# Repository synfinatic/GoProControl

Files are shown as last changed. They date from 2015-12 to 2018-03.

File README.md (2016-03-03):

# GoProControl

## About

I wanted an easy way to syncronize my GoPro videos with the data generated from
my data logger.  In the past, I've done this manually with
[DashWare](http://www.dashware.net), but it is a tedious manual process to get
them syncronized.  There had to be a better way!

I realized that many GoPro's (GoPro3 Silver/Black, GoPro4, etc) have built in
WiFi and we all know about the iPhone and Android apps.  So clearly there was a
way to controll them via WiFi.

GoProControl is a simple box you can plug into your car or motorcycle and
connect to your datalogger's digital output or input sensor.  I use the
inexpensive [ESP8266](http://www.esp8266.com/) to control the a GoPro.  In the
future, I hope to be able to control multiple GoPro's like the [GoPro
Remote](http://shop.gopro.com/accessories/smart-remote/ARMTE-002.html) can.

## How it works

GoProControl has 4 pins:

 1. +5-12V
 2. GND
 3. Digital Input 
 4. Digital Ouput
 
When GoProControl is turned on, it will send a signal to the GoPro to also turn
on- which may take a few seconds.  When the Digital Input is connected to
ground (GND) it will tell the GoPro to start recording. 

When the Digital Input is disconnected from ground (floating or +3.3-12V) it
will tell the GoPro to stop recording.  You should configure your GoPro to
auto-off after 60seconds to save battery.

Note, when the Digital Input is connected to ground, the Digital Output will be
driven to 3.3V.  This is so if your data logger does not have an output channel
you can control, you can use a simple toggle switch to both turn on the GoPro
and mark the time when recording started in your data logger using an input
channel on your data logger.

**Note:** If you have the option of powering this by 5 or 12V, use 5V.  If
using your vehicle's battery, be sure it is switched with the ignition to
prevent draining your battery as this circuit uses ~330mA.

## Programming

The GoProControl board has an onboard connector for programming via a FTDI
cable.  This cable should provide 5V of power and can use either 3.3V or 
5V for signalling.

Configure your GoPro WiFi for "App Mode" and define a SSID and WiFi Password.

Before programming your GoProController, you first need to edit 
**src/goprocontrol/goprocontrol.ino** and edit the SSID and WIFI_PASSWORD
to match your GoPro's settings.

In order to program your GoProController, you will need to start the Arduino
application and figure out what serial speed (baud) your ESP8266 communicates
at.  Older boards run at 9600, while newer boards seem to run at 115200.  

Once you have figured out the serial speed, configure Arduino for a 
"Generic ESP8266 Module" and the upload speed to the same speed.  Then, 
with the board powered up:

 1. Press and hold the PROG button
 2. Press and release the RST button
 3. Release the PROG button
 4. Uplaod the sketch via the Arduino application

## Links Links to projects or information that was critical to me creating this
project.  Thank you!

 * [GoProWiFiHack](https://github.com/KonradIT/goprowifihack)
 * [GoProController](https://github.com/joshvillbrandt/GoProController)
 * [GoProHero](https://github.com/joshvillbrandt/goprohero)
 * [GoProControllerUI](https://github.com/joshvillbrandt/GoProControllerUI)

## License

GoProControl is GPLv3

## Trademarks

GoPro, GoPro3 and GoPro4 are trademark [GoPro](http://www.gopro.com).

GoProControl is not affiliated with GoPro in any way.

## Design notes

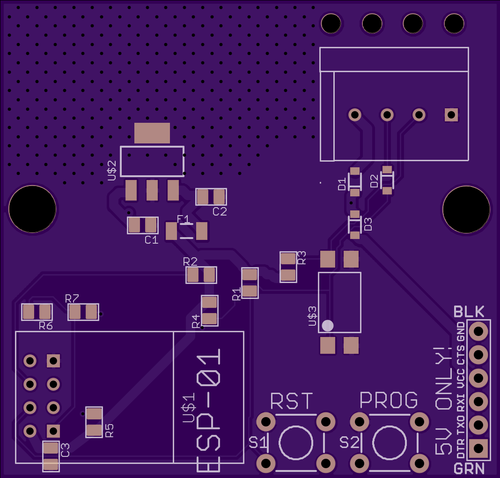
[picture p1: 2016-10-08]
images/board-top.png

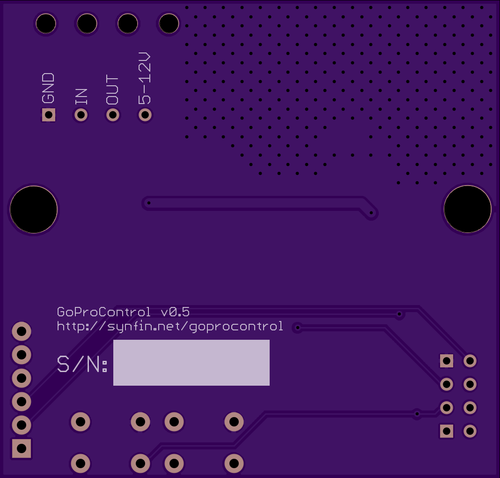
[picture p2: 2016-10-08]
images/board-bottom.png

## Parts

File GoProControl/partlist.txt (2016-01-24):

Partlist

Exported from goprocontrol.sch at 1/23/16 4:04 PM

EAGLE Version 7.5.0 Copyright (c) 1988-2015 CadSoft

Assembly variant: 

Part     Value                        Device                                      Package             Library                    Sheet

C1       1uf                          CERAMIC-1UF-25V-10%-X7R(0805)               C0805               Seeed-OPL-Capacitor        1
C2       .01uf                        CERAMIC-1UF-25V-10%-X7R(0805)               C0805               Seeed-OPL-Capacitor        1
D1       B5817WS                      SCHOTTKY-DIODE                              SOD-323             synfinatic                 1
D2       B5817WS                      SCHOTTKY-DIODE                              SOD-323             synfinatic                 1
D3       B5817WS                      SCHOTTKY-DIODE                              SOD-323             synfinatic                 1
JP1      FTDI_BASICPTH                FTDI_BASICPTH                               FTDI_BASIC          SparkFun-Connectors        1
JP2                                   M03PTH                                      1X03                SparkFun-Connectors        1
JP3      PTSA-1.5/4-3.5FOST-TE-3.5-4P PTSA-1.5/4-3.5FOST-TE-3.5-4P                TERM-4P-3.5         synfinatic                 1
R1       1k                           SMD-RES-10K-1%-1/8W(0805)                   R0805               Seeed-OPL-Resistor         1
R2       1k                           SMD-RES-10K-1%-1/8W(0805)                   R0805               Seeed-OPL-Resistor         1
R4       1k                           SMD-RES-10K-1%-1/8W(0805)                   R0805               Seeed-OPL-Resistor         1
R5       1k                           SMD-RES-10K-1%-1/8W(0805)                   R0805               Seeed-OPL-Resistor         1
R6       10K                          SMD-RES-10K-1%-1/8W(0805)                   R0805               Seeed-OPL-Resistor         1
R7       22K                          SMD-RES-22K-5%-1/8W(0805)                   R0805               Seeed-OPL-Resistor         1
S1       RESET                        SWITCH-MOMENTARY-2PTH                       TACTILE-PTH         SparkFun-Electromechanical 1
S2       PROG                         SWITCH-MOMENTARY-2PTH                       TACTILE-PTH         SparkFun-Electromechanical 1
U$1      ESP01                        ESP01                                       ESP01               esp8266modules             1
U$2      POLOLU-D24V5F3               POLOLU-D24V5FD24V5F                         POLOLU-D24V5FX      synfinatic                 1
U$3      LTV-816S                     SMD-PHOTOCOUPLER-5KV-LTV-816S(4P-4.6X6.5MM) SMD4-2.54-4.6X6.5MM Seeed-OPL-Transistor       1

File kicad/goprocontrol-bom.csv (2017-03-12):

Source | /Users/aturner/GIT/gopro-control/kicad/goprocontrol.sch
Kicad Rev | Eeschema 4.0.5
Generated Date | Saturday | March 11 | 2017 'PMt' 07:09:48 PM
Title | GoProControl with Adjustable Delay Timer
Company | Aaron Turner <synfinatic@gmail.com>
Revision | v2.0
Date Issue | 2017-03-05
Comment | https://synfin.net/goprocontrol
Comment | Advanced GoProControl
Comment | GoProControl with Power Control
Reference | Value | Library | Library Ref
P1 | CONN_01X06 | conn | CONN_01X06
U2 | ESP-01v090 | ESP8266 | ESP-01v090
SW2 | Prog | switches | SW_Push
SW1 | Reset | switches | SW_Push
R2 | 1k | device | R
R1 | 1k | device | R
C2 | 1uf | device | C
U3 | D24V5F3 | synfinatic | D24V5Fx
R13 | 1k | device | R
C5 | .01uf | device | C
U1 | NE555 | linear | NE555
RV1 | 500k | device | POT_TRIM
Q3 | MMBT3906 | transistors | MMBT3906
Q4 | MMBT3906 | transistors | MMBT3906
Q1 | MMBT3904 | transistors | MMBT3904
Q2 | MMBT3904 | transistors | MMBT3904
C1 | 0.1uf | device | C
R3 | 100k | device | R
C4 | 100uf | device | CP
R6 | 2.2k | device | R
D2 | 1n4148 | device | D
R11 | 2.2k | device | R
R9 | 10k | device | R
R10 | 2.2k | device | R
R7 | 10k | device | R
R8 | 2.2k | device | R
C3 | 0.1uf | device | C
Q5 | IRLML6344 | device | Q_NMOS_GSD
R12 | 1k | device | R
ROpt1 | 100k | device | R
FTDIProg1 | FTDI | synfinatic | FTDI
D3 | B5817WS | device | D_Schottky
D4 | B5817WS | device | D_Schottky
P2 | CONN_01X02 | conn | CONN_01X02

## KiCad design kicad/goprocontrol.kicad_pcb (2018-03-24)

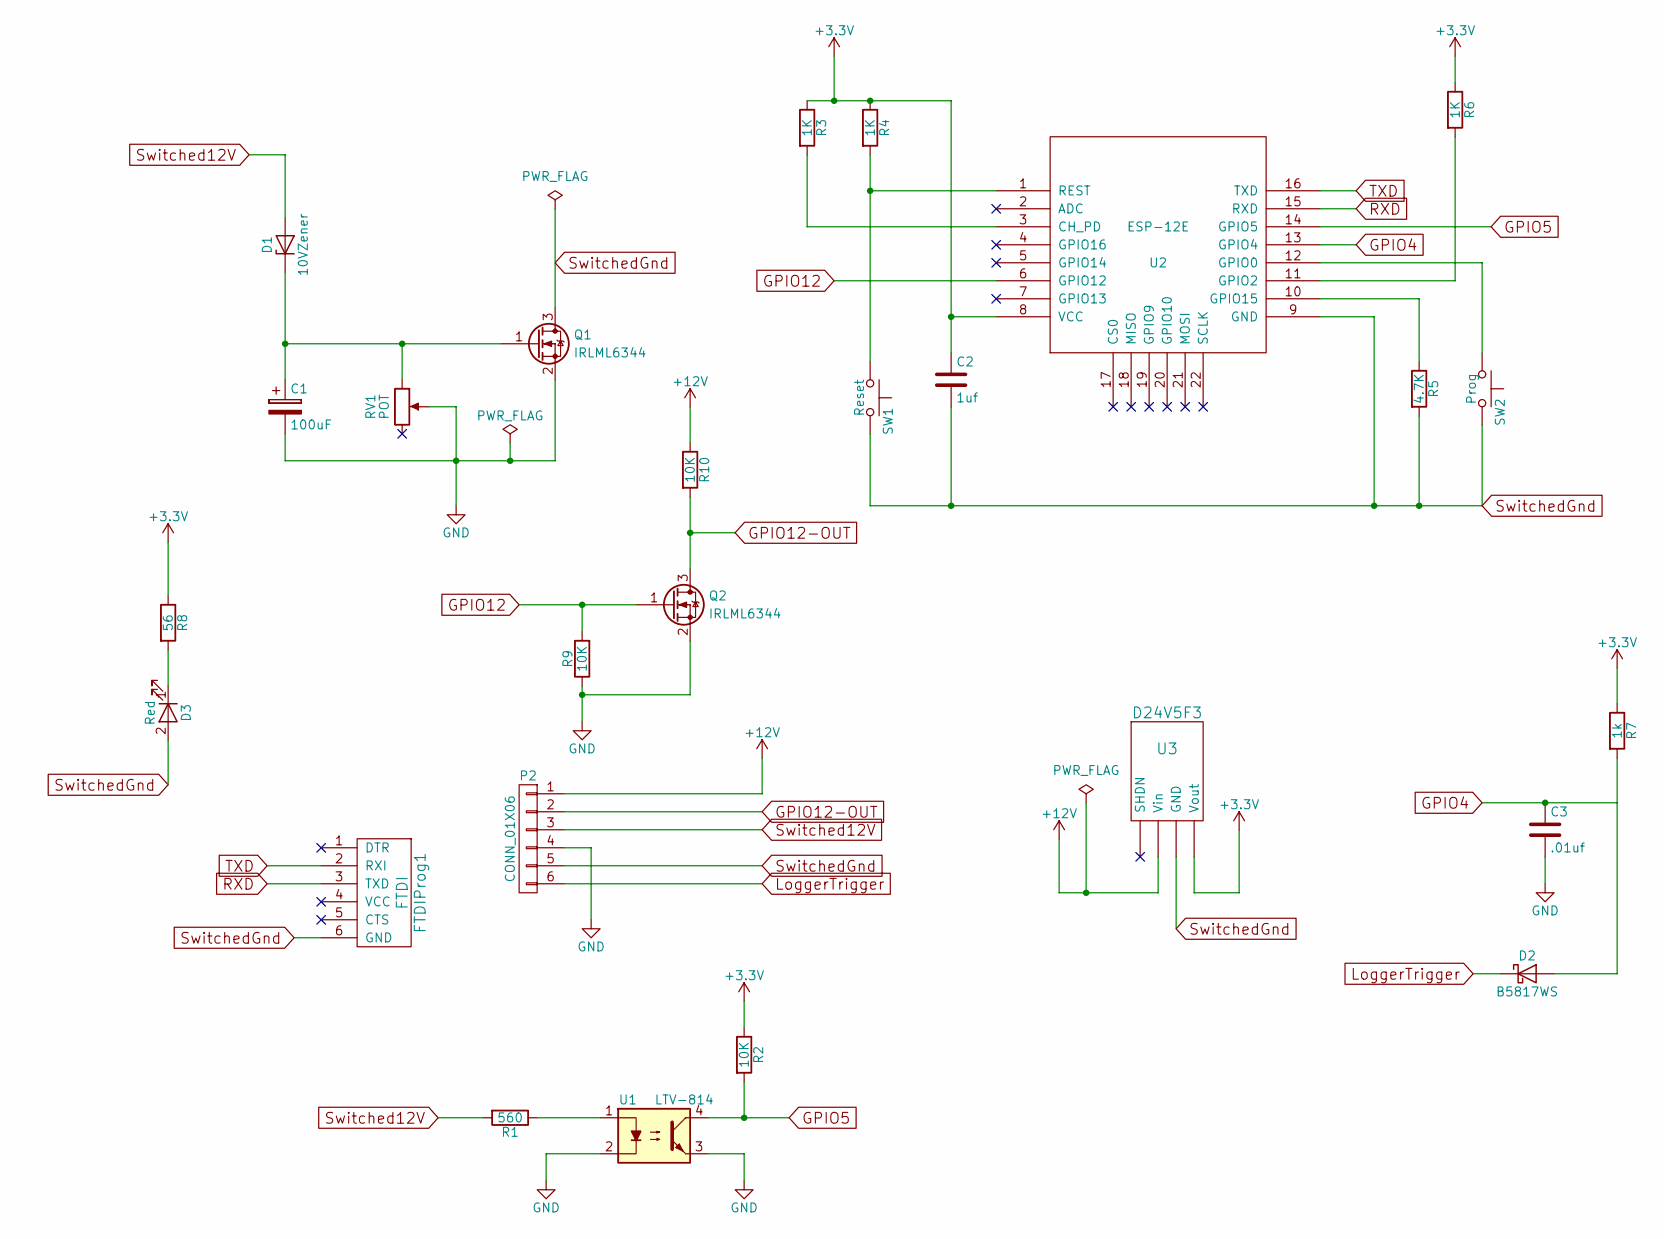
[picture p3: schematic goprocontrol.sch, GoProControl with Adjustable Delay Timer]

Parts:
C1: 100uF; CP_Elec_6.3x7.7
C2: 1uf; C_0805_HandSoldering
C3: .01uf; C_0805_HandSoldering
D1: 10VZener; D_SOD-123F
D2: B5817WS; SOD-323_HandSoldering
D3: Red; LED_0805_HandSoldering
FTDIProg1: FTDI; FTDIHeader
P2: CONN_01X06; PhoenixContact_MSTBA-G_06x5.08mm_Angled
Q1, Q2: IRLML6344; SOT-23_Handsoldering
R1: 560; R_0805_HandSoldering
R2, R9, R10: 10K; R_0805_HandSoldering
R3, R4, R6: 1K; R_0805_HandSoldering
R5: 4.7K; R_0805_HandSoldering
R7: 1k; R_0805_HandSoldering
R8: 56; R_0805_HandSoldering
RV1: POT; Potentiometer_Bourns_3296W_3-8Zoll_Inline_ScrewUp
SW1: Reset; SPST-SMD-6x3.5
SW2: Prog; SPST-SMD-6x3.5
U1: LTV-814; Optocoupler_SMD_LTV-817S
U2: ESP-12E; ESP-12E-SMD
U3: D24V5F3; D24V5Fx

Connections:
+3V3: C2.1, R2.1, R3.1, R4.1, R6.1, R7.1, R8.1, U2.8 (VCC), U3.4 (Vout)
+12V: P2.1, R10.1, U3.2 (Vin)
GND: C1.2, C3.2, P2.4, Q1.2 (S), Q2.2 (S), R9.1, RV1.2, U1.2, U1.3
GPIO4: C3.1, U2.13 (GPIO4)
GPIO5: R2.2, U1.4, U2.14 (GPIO5)
GPIO12: Q2.1 (G), R9.2, U2.6 (GPIO12)
GPIO12-OUT: P2.2, Q2.3 (D), R10.2
LoggerTrigger: D2.1 (K), P2.6
unnamed: C1.1, D1.1 (K), Q1.1 (G), RV1.1
unnamed: D2.2 (A), R7.2
unnamed: D3.1 (K), R8.2
unnamed: R1.1, U1.1
unnamed: R3.2, U2.3 (CH_PD)
unnamed: R4.2, SW1.1, U2.1 (REST)
unnamed: R5.1, U2.10 (GPIO15)
unnamed: R6.2, U2.11 (GPIO2)
unnamed: SW2.1, U2.12 (GPIO0)
RXD: FTDIProg1.3 (TXD), U2.15 (RXD)
Switched12V: D1.2 (A), P2.3, R1.2
SwitchedGnd: C2.2, D3.2 (A), FTDIProg1.6 (GND), P2.5, Q1.3 (D), R5.2, SW1.2, SW2.2, U2.9 (GND), U3.3 (GND)
TXD: FTDIProg1.2 (RXI), U2.16 (TXD)

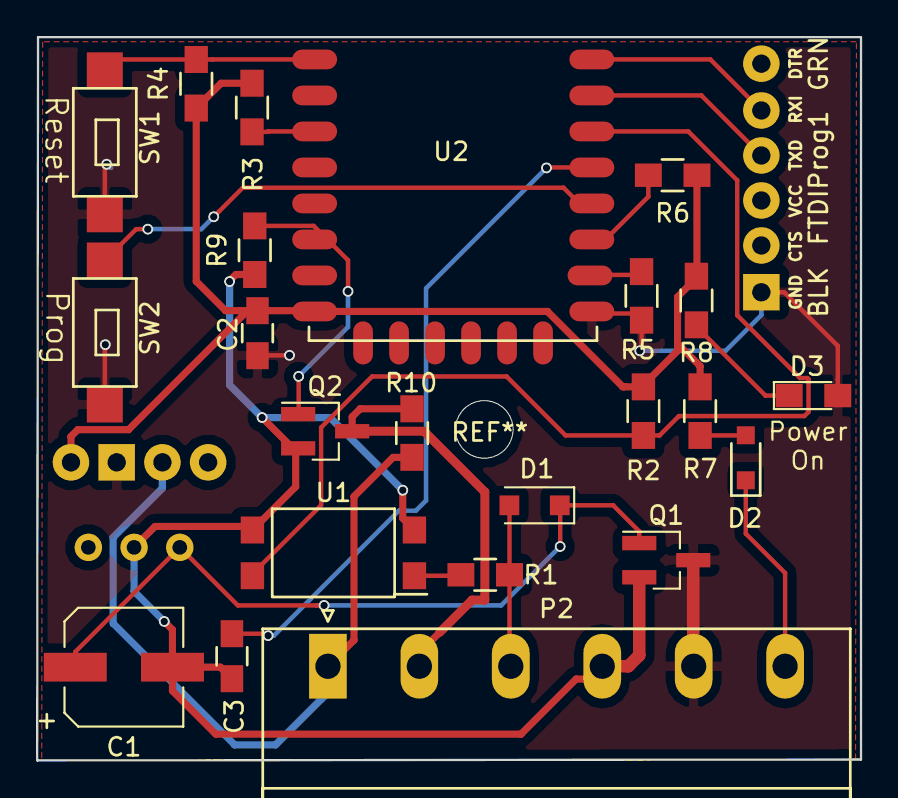
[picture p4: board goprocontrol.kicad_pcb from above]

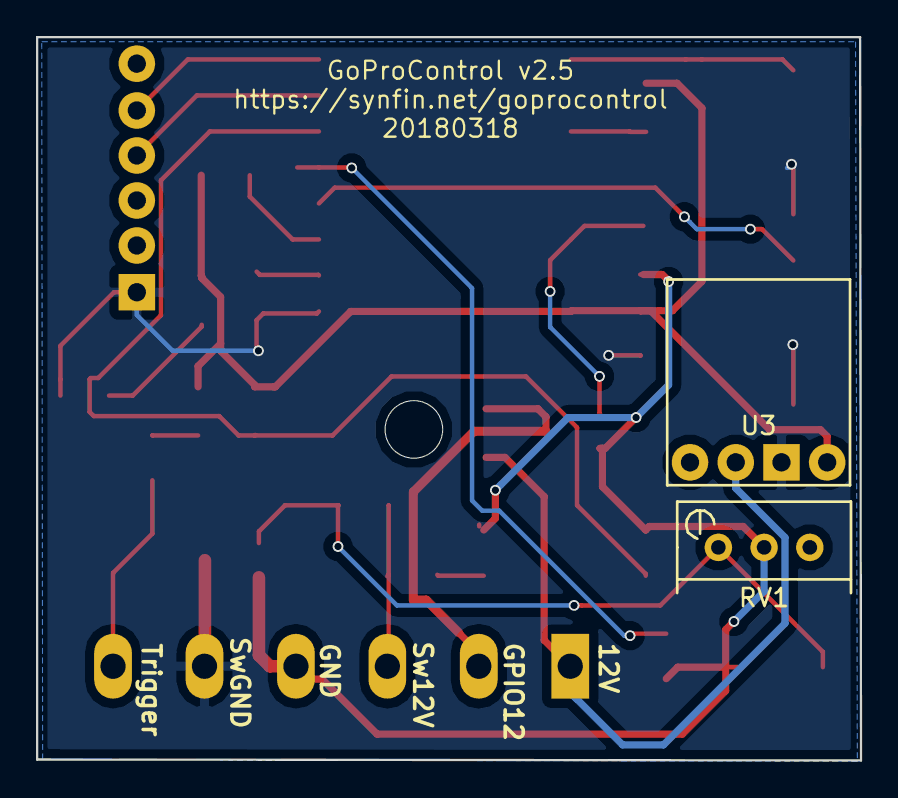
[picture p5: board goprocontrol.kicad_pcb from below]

Board: 2 copper layers, 45.8 x 40.2 mm, 26 parts (2 on the bottom side), 21 nets.

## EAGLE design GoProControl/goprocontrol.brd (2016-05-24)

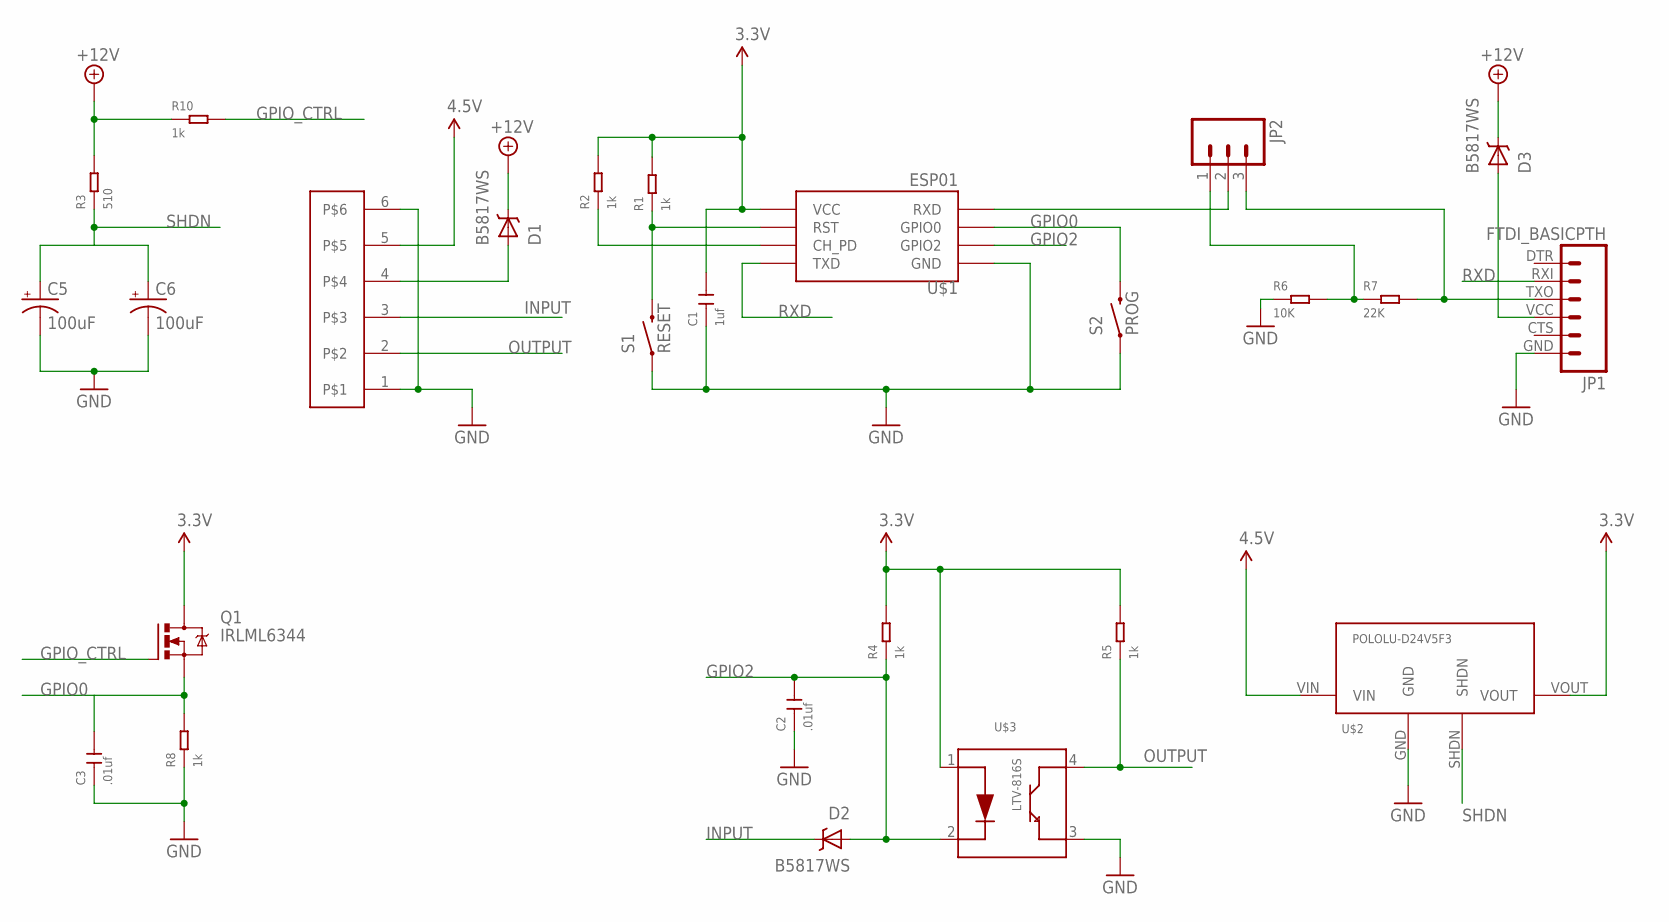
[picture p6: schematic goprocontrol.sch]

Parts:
C1: 1uf; C0805
C2, C3: .01uf; C0805
C5, C6: 100uF; CPOL-RADIAL-100UF-25V
D1, D2, D3: B5817WS; SOD-323
JP1: FTDI_BASICPTH; FTDI_BASIC
JP2: M03PTH; 1X03
Q1: IRLML6344; SOT23
R1, R2, R4, R5, R8, R10: 1k; R0805
R3: 510; R0805
R6: 10K; R0805
R7: 22K; R0805
S1: RESET; TACTILE-PTH
S2: PROG; TACTILE-PTH
U$1: ESP01
U$2: POLOLU-D24V5F3; POLOLU-D24V5FX
U$3: LTV-816S; SMD4-2.54-4.6X6.5MM
U$4: TERM-BLOCK-P6-3.5; TERM-6P-3.5

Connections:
3.3V: C1.2, Q1.3 (D), R1.2, R2.2, R4.2, R5.2, U$1.VCC, U$2.VOUT, U$3.1 (ANODE)
3.3V-TX: JP1.TXO (3), JP2.3, R7.2
5V-TX: JP2.1, R6.2, R7.1
+12V: D1.C1 (C), D3.C1 (C), R3.2, R10.1
GND: C1.1, C2.1, C3.1, C5.2 (-), C6.2 (-), JP1.GND (6), R6.1, R8.1, S1.1, S2.1, U$1.GND, U$2.GND, U$3.3 (EMITER), U$4.1, U$4.6
GPIO0: C3.2, Q1.2 (S), R8.2, S2.3 (2), U$1.GPIO0
GPIO2: C2.2, D2.A1 (A), R4.1, U$1.GPIO2, U$3.2 (CATHODE)
GPIO_CTRL: Q1.1 (G), R10.2
INPUT: D2.C1 (C), U$4.3
unnamed: R2.1, U$1.CH_PD
unnamed: R1.1, S1.3 (2), U$1.RST
unnamed: D3.A1 (A), JP1.VCC (4)
unnamed: D1.A1 (A), U$4.4
OUTPUT: R5.1, U$3.4 (COLLECTOR), U$4.2
RXD: JP1.RXI (2), U$1.TX (TXD)
SHDN: C5.1 (+), C6.1 (+), R3.1, U$2.SHDN
TXD: JP2.2, U$1.RX (RXD)
V_BATT: U$2.VIN, U$4.5

Board: 2 copper layers, 26 parts (0 on the bottom side), 18 nets, no tracks yet.

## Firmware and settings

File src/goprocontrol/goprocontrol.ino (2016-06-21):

/*
 * GoProControl
 *
 * Software for ESP8266 (ESP-01) to control a GoPro camera via
 * WiFi.  Tested with GoPro 3+ Silver/Black
 *
 * Make sure you've installed:
 *  - Arduino IDE v1.6.5+ (http://www.arduino.cc)
 *  - ESP8266 for Arduino (https://github.com/esp8266/Arduino) 
 */
#define SERIAL_SPEED 115200        // Set this to match your ESP8266 serial speed
#define GOPRO_DEBUG_WIFI 0         // Enable (1) or disable (0) debugging
#define SSID_NAME "ADTGoProBlack"  // SSID of your GoPro
#define WIFI_PASSWORD "falcon123"  // WiFi Password


#include <Arduino.h>

#include <ESP8266WiFi.h>
#include <ESP8266WiFiMulti.h>
#include <ESP8266HTTPClient.h>
#include "goprocontrol.h"

#define USE_SERIAL Serial

ESP8266WiFiMulti WiFiMulti;
char request_str[45];

typedef enum {
    START,
    STOP,
    NO_CHANGE,
    NONE
} Recording;

Recording recording = NO_CHANGE;
Recording last_mode = NONE;

/*
 * Send a HTTP request up to <retries> times with a <delay_ms> delay.
 * If retries < 0, then we will retry forever.  We'll only print an error 
 * every 10 times
 */
bool
send_request(const char *request_fmt, int retries = 5, int delay_ms = 100) {
    int httpCode, status;
    unsigned int times = 0;
    HTTPClient http;

    snprintf(request_str, 44, request_fmt, WIFI_PASSWORD);
    USE_SERIAL.printf("Sending: %s\n", request_str);

    while (((times < retries) && retries > 0) || (retries < 0)) {
        USE_SERIAL.printf("Trying run()\n");
        USE_SERIAL.flush();
        status = WiFiMulti.run();
        if ((status == WL_CONNECTED)) {
            USE_SERIAL.printf("Trying begin()\n");
            USE_SERIAL.flush();
            http.begin(GOPRO_HOST, GOPRO_PORT, request_str);
            USE_SERIAL.printf("Trying GET()\n");
            USE_SERIAL.flush();
            httpCode = http.GET();
            if (httpCode == HTTP_CODE_OK) {
                http.end();
                USE_SERIAL.printf("OK\n");
                USE_SERIAL.flush();
                return true;
            } else if (times % 10 == 0) {
                USE_SERIAL.printf("[%u] HTTP GET failed with: %d\n", times, httpCode);
                USE_SERIAL.flush();
            }
        } else if (times % 10 == 0) {
            USE_SERIAL.printf("Not connected to GoPro WiFi: %d\n", status);
            USE_SERIAL.flush();
        }
        times ++;
        delay(delay_ms);
    }

    http.end();
    USE_SERIAL.printf("Failed %d times to send request: %s", retries, request_fmt);
    USE_SERIAL.flush();
    return false;
}

void 
setup() {
    int status;

    pinMode(GPIO, INPUT);

    USE_SERIAL.begin(SERIAL_SPEED);
#ifdef GOPRO_DEBUG_WIFI
    USE_SERIAL.setDebugOutput(true);
#endif

    USE_SERIAL.println();
    USE_SERIAL.println();
    USE_SERIAL.println();

    for(uint8_t t = 4; t > 0; t--) {
        USE_SERIAL.printf("[SETUP] WAIT %d...\n", t);
        USE_SERIAL.flush();
        delay(1000);
    }

    USE_SERIAL.printf("Connecting to %s\n", SSID_NAME);
    WiFiMulti.addAP(SSID_NAME, WIFI_PASSWORD);
    status = WiFiMulti.run();
    if (status == WL_CONNECTED) {
        USE_SERIAL.printf("Connected!\n");
    } else {
        USE_SERIAL.printf("Not connected: %d\n", status);
    }
    WiFiMulti.run();
    send_request(GOPRO_ON, -1, 1000);  // Blocks until we turn on the GoPro
}


/*
 * Loop forever looking to see if we should start/stop recording
 */
void
loop() {
    if (digitalRead(GPIO) == HIGH) {
        recording = STOP;
    } else {
        // we record when it goes low!
        recording = START;
    }

    if (recording != last_mode) {
        USE_SERIAL.printf("Changing modes %u -> %u\n", last_mode, recording);
        last_mode = recording;

        if (recording == START) {
            USE_SERIAL.printf("Starting recording...\n");
            if (send_request(GOPRO_RECORD)) {
                recording = NO_CHANGE;
            }
        } else if (recording == STOP) {
            USE_SERIAL.printf("Stopping recording...\n");
            if (send_request(GOPRO_STOP)) {
                recording = NO_CHANGE;
            }
        }
    }
}

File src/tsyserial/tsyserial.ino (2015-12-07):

/*
 * Teensy Serial Application for Teensy 3.x => ESP8266
 *
 * Uses HWSerial Port 0 on Teensy 3.x to talk
 * to ESP8266.  Everything you read/write on the /dev/tty.usb*
 * port the Teensy exposes will be read/write to the ESP8266-
 * basically, it's an programmable $18 FTDI cable. :)
 *
 * Be sure to enable "Both NL and CR" in the Arduino
 * terminal if you're going to talk AT commands to the ESP8266!
 */

#include <Arduino.h>
// ESP8266 serial port speed.  Try: 115200, 9600, 57600
#define ESPSERIAL_SPEED 115200
#define LED 13

void setup() {
    Serial.begin(9600);
    Serial1.begin(ESPSERIAL_SPEED);
    pinMode(LED, OUTPUT);
}

uint32_t last = 0; 
bool led_mode;

void loop() {
    char byte;
    uint32_t now;

    if (Serial.available()) {
        byte = Serial.read();
        Serial1.write(byte); 
    } else if (Serial1.available()) {
        byte = Serial1.read();
        Serial.write(byte);
    }
    now = millis();
    if (now > (last + 1000)) {
        led_mode = !led_mode;
        digitalWrite(LED, led_mode);
        last = now;
    }

}

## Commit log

2015-12-06 initial commit. Basic board design, but want to change it
    [goprocontrol.brd, goprocontrol.sch]
2015-12-06 update board to fit in sv650 ecu decoder box
    [goprocontrol.brd]
2015-12-06 added ground planes top & bottom
    [goprocontrol.brd]
2015-12-06 v0.1 release
    Fixed outline for term block and labled pins
    [goprocontrol.brd, goprocontrol.sch]
2015-12-06 v0.2 small tweaks
    - trim board to better fit case
    - verify all DRC/ERC
    [goprocontrol.brd, goprocontrol.sch]
2015-12-06 Better describe out circuit works
2015-12-06 v0.3
    - heat sink vias are now 0.35mm and have no exposed copper
    - 2x the number of heat sink vias
    - improved labels
    [goprocontrol.brd]
2015-12-06 v0.4 fix diode pads
    My old sod-323 and sod-123 pads always seemed a bit wrong/too small
    these new pads are better.
    [goprocontrol.brd, goprocontrol.sch]
2015-12-07 Helper program to play with ESP8266 using a Teensy 3.x
    Ok, this is lame, but none of my ESP8266 will talk via the
    FTDI cable I have so I ended up using an old Teensy 3.0 I had laying
    around to do the USB->Serial 3.3V converstion. It's lame, but it works.
2015-12-16 Add a 500ma PTC fuse to protect things
    [goprocontrol.brd, goprocontrol.sch]
2015-12-16 Add pullup on GPIO0 for better reliability and switch to 10K pullups
    [goprocontrol.brd, goprocontrol.sch]
2015-12-16 small cleanup to .sch
    [goprocontrol.sch]
2015-12-16 First pass at some code:
    - Tries to connect to the GoPro WiFi AP
    - Tries to turn on the GoPro
    - When GPIO2 goes low, we start recording
    - When GPIO2 goes high, we stop recording
    Totally untested right now because I seem to be missing the compiler.
    :-/
    [goprocontrol.ino]
2015-12-18 Update PCB to v0.5
    - Switch to using more common 5V FTDI (VCC & signal)
    - Use Schottky diodes to protect reverse polarity and
    to make sure we don't send 12V onto the FTDI VCC line
    - Add 1uF cap to VCC on ESP8266 to stabilize things
    Still would be a good idea to protect against the FTDI
    cable being inserted backwards and putting 5V onto RXD
    [goprocontrol.brd, goprocontrol.sch]
2015-12-30 Update PCB to v0.6
    - Replace LDO with a switching module
    - Update readme file
    [goprocontrol.brd, goprocontrol.sch]
2016-01-23 Update board to v0.7
    - Fixes FTDI RX/TX reversal
    - Fixes GPIO2 pullup
    - Rotated termblock
    - Still needs to fix term block part to match
    [goprocontrol.brd, goprocontrol.sch]
2016-01-24 v0.8 - ordered!
    - Tweaked footprints & labels
    - Changed term block outline to match OST TE 3.5mm
    - Added parts list
    [goprocontrol.brd, goprocontrol.sch]
2016-03-03 Update code to work better (kinda)
    Code looks like it should work, but it crashes???
    [goprocontrol.ino]
2016-03-03 Update PCB to v0.9
    - Just changed silk screen to swap Input/Output labels to
    match the actual pins!
    [goprocontrol.brd, goprocontrol.sch]
2016-05-24 small board tweaks
    [goprocontrol.brd, goprocontrol.sch]
2016-06-21 Basic working code
    Seems to work, but board needs to be modified to support
    a automatic shutdown
2016-10-08 renderings of v0.5 of the board
2017-02-26 Redesign board with KiCad
    Utilize 555 timer to do a delayed power off
    for the circuit and the data logger. Removes
    the output signal.
    [goprocontrol-bom.csv, goprocontrol.kicad_pcb, goprocontrol.sch]
2017-03-12 Design new v2.0 board
    Still ESP8266 based
    Add delaytimer v1.1 circuit for power control
    [goprocontrol.kicad_pcb, goprocontrol.sch]
2017-03-12 update BOM
    [goprocontrol-bom.csv]
2017-10-15 GoProControl v2.1 ordered
    [goprocontrol.kicad_pcb, goprocontrol.sch]
2018-02-18 Rev board to v2.2
    - Switch to using ESP12E
    - Switch to using OptoIsolator + ESP power off detection
    - Using Pot to control power off delay
    [goprocontrol.kicad_pcb, goprocontrol.sch]
2018-03-11 v2.3 Board
    - Larger holes for 1x6 connector
    - Move 3.3V regulator out of the way
    - clean up traces
    - remove 3.3V FTDI selector
    - Move Prog switch
    - Better GND/SW-GND for MOSFET
    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
    [goprocontrol.kicad_pcb, goprocontrol.sch]
2018-03-24 v2.5 of the board
    - Move main connector to front
    - Use MOSFET to drive GPIO12 like MXL2
    - Larger traces for Switched Ground
    [goprocontrol.kicad_pcb, goprocontrol.sch]

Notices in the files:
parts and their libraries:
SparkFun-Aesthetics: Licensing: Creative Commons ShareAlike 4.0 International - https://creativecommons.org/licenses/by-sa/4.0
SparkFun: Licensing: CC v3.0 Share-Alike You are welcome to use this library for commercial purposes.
